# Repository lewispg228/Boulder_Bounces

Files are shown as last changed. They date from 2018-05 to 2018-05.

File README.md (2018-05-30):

# Boulder Bounces
The Museum of Boulder exhibit designers have paired with SparkFun to create Boulder Bounces: a mashup of Simon Says on trampolines. With sounds and spot lights triggering for every jump in the room, the exhibit is a bouncy blast for all ages.

Also includes slightly different code for the "Mighty Mini" and "Hop & Hear".

For a more in depth written post about the design choices, challenges, and future developments please visit the Enginursday blog post here:

https://www.sparkfun.com/news/2696

Visit this website for more info and links to all the products used in this project:

https://www.sparkfun.com/boulderbounces

To learn more about the Museum of Boulder and buy tickets please visit their website here:

https://www.museumofboulder.org

SparkFun products used in this project:

[Arduino Pro Mini 328 - 5V/16MHz](https://www.sparkfun.com/products/11113)

[Ultrasonic Sensor - HC-SR04](https://www.sparkfun.com/products/13959)

[Tsunami Super WAV Trigger](https://www.sparkfun.com/products/13810)

[SparkFun Beefcake Relay Control Kit Ver. 2.0](https://www.sparkfun.com/products/13815)

[SparkFun Music Instrument Shield](https://www.sparkfun.com/products/10587)

[7-Segment Display - 6.5" (Red)](https://www.sparkfun.com/products/8530)

[SparkFun Large Digit Driver](https://www.sparkfun.com/products/13279)

[SparkFun Noisy Cricket Stereo Amplifier - 1.5W](https://www.sparkfun.com/products/14475)

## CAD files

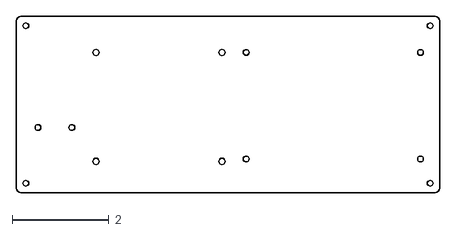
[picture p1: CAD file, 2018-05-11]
HARDWARE/MAIN_BASE/MAIN_BASE_2.dxf
8.75 x 3.65

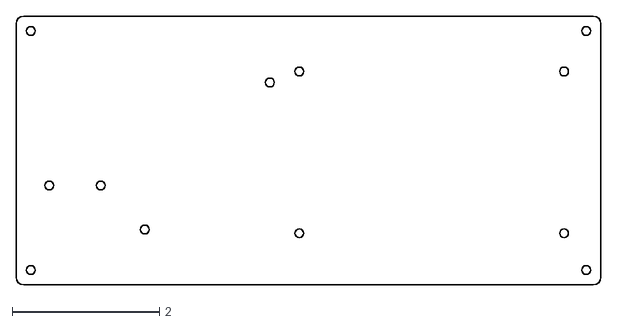
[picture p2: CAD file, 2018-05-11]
HARDWARE/MAIN_BASE/MAIN_BASE.dxf
7.95 x 3.65

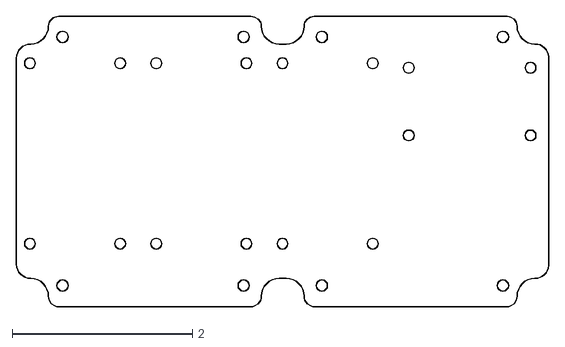
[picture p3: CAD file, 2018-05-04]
HARDWARE/Trampoline_Lights_BASE/Trampoline_Lights_BASE.dxf
5.90 x 3.22

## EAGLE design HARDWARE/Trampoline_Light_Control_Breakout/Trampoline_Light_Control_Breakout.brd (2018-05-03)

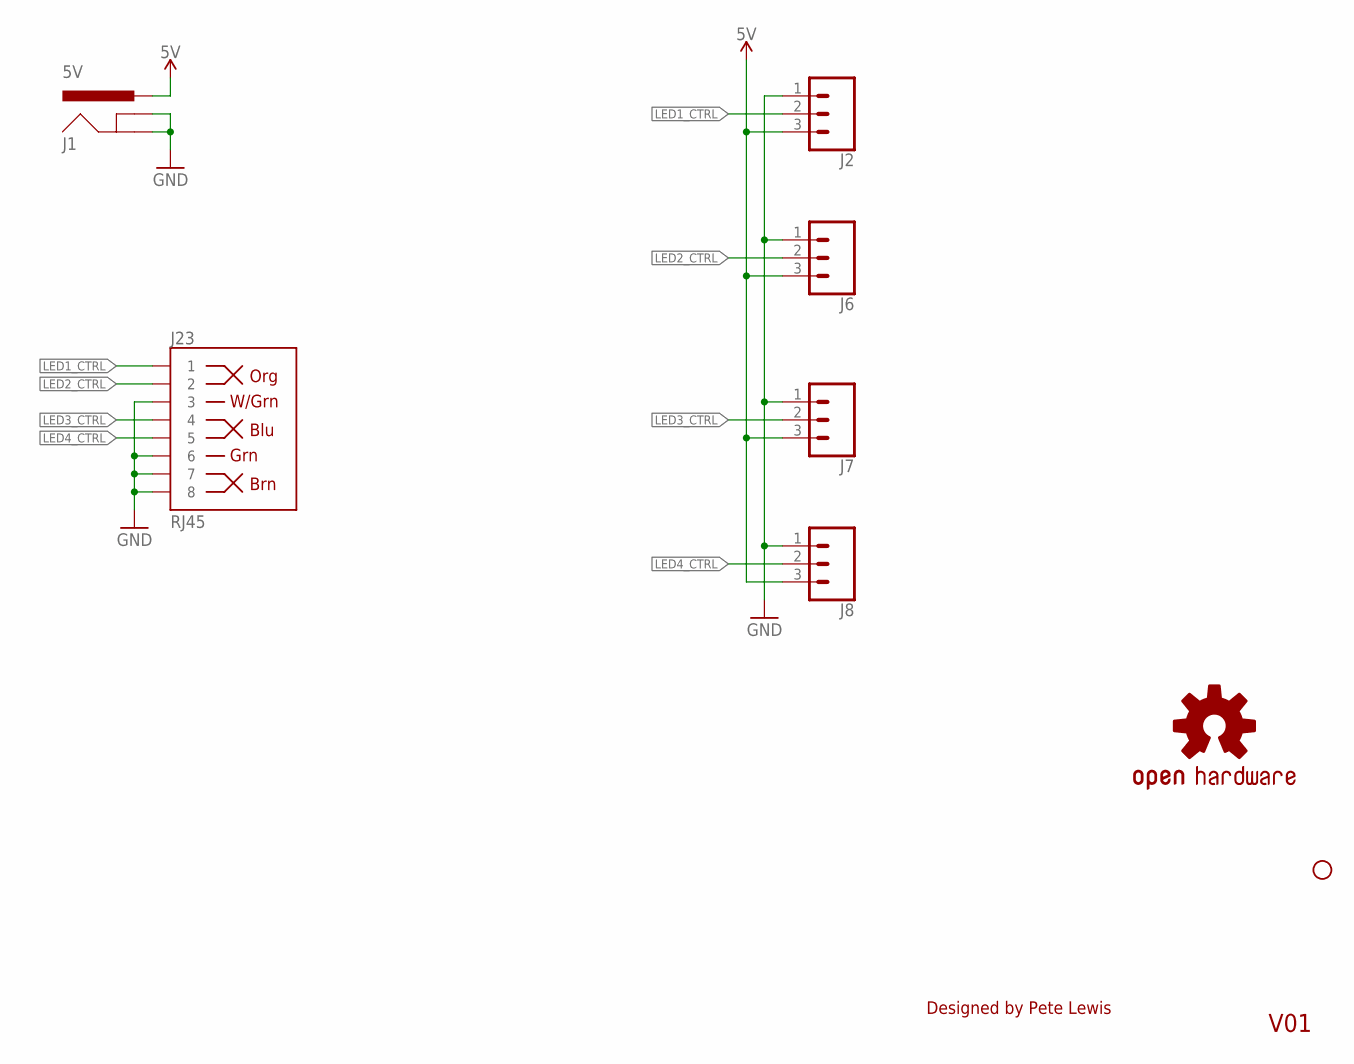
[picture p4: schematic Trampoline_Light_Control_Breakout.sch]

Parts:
J1: 5V; POWER_JACK_PTH_LOCK
J2, J6, J7, J8: CONN_03LONGPADS; 1X03_LONGPADS
J23: RJ45; RJ45-8
JP1: STAND-OFFTIGHTER; STAND-OFF-TIGHTER
LOGO2: OSHW-LOGOS; OSHW-LOGO-S

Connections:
GND: J1.GND, J1.GNDBREAK, J2.1, J6.1, J7.1, J8.1, J23.3, J23.6, J23.7, J23.8
LED1_CTRL: J2.2, J23.1
LED2_CTRL: J6.2, J23.2
LED3_CTRL: J7.2, J23.4
LED4_CTRL: J8.2, J23.5
VCC: J1.PWR, J2.3, J6.3, J7.3, J8.3

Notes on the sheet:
V01
Designed by Pete Lewis

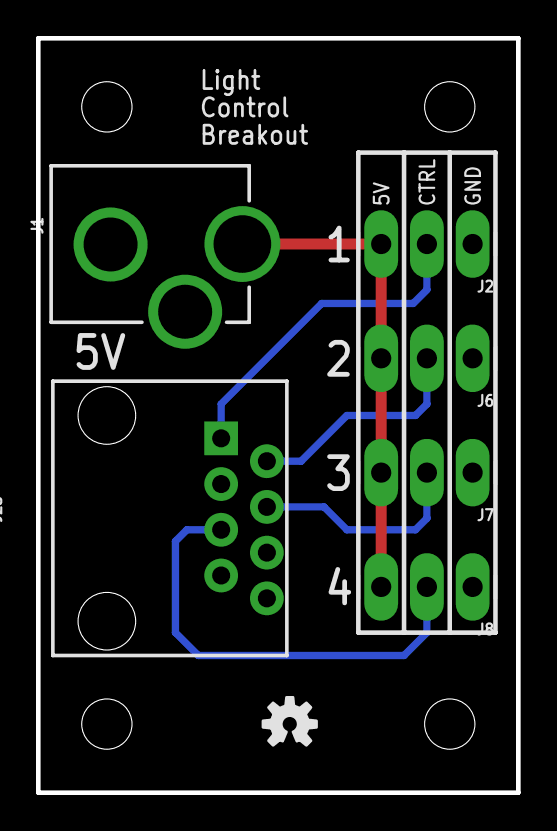
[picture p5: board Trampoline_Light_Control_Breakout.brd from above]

Board: 2 copper layers, 26.7 x 41.9 mm, 11 parts (0 on the bottom side), 6 nets.

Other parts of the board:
JP2, JP3, JP7: STAND-OFFTIGHTER; STAND-OFF-TIGHTER

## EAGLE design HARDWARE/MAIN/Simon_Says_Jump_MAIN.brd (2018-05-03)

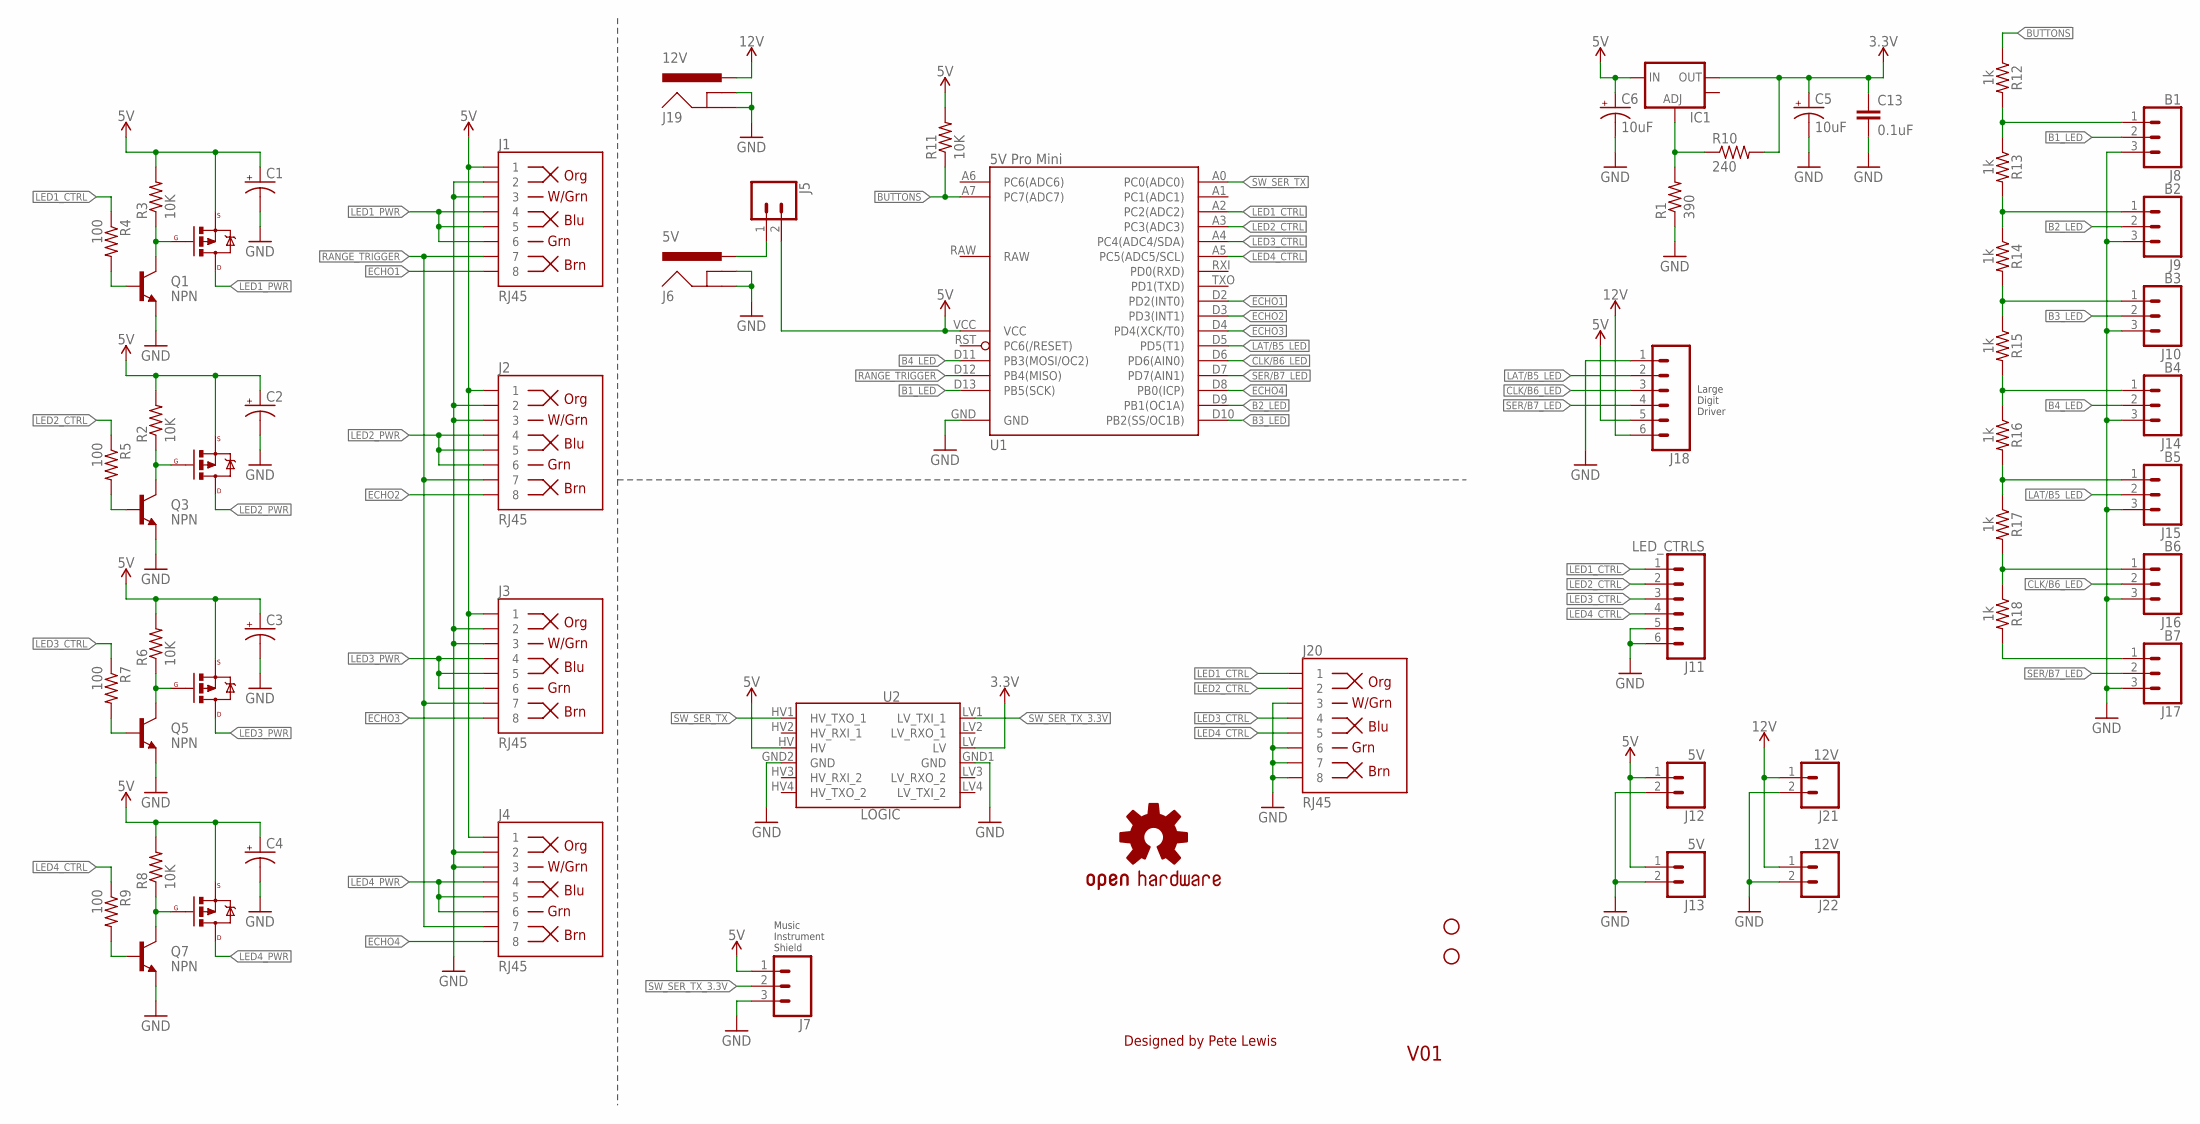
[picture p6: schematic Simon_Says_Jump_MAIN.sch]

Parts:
C1, C2, C3, C4: CAP_POLCPOL-RADIAL-10UF-25V-KIT; CPOL-RADIAL-10UF-25V-KIT
C5, C6: 10uF; EIA3216
C13: 0.1uF; 0603-CAP
IC1: V_REG_LM1117SOT223; SOT223
J1, J2, J3, J4, J20: RJ45; RJ45-8
J5: CONN_02PTH3; 1X02_LONGPADS
J6: 5V; POWER_JACK_PTH_LOCK
J7: CONN_03LONGPADS; 1X03_LONGPADS
J8: B1; 1X03_LONGPADS
J9: B2; 1X03_LONGPADS
J10: B3; 1X03_LONGPADS
J11: LED_CTRLS; 1X06_LONGPADS
J12, J13: 5V; 1X02_LONGPADS
J14: B4; 1X03_LONGPADS
J15: B5; 1X03_LONGPADS
J16: B6; 1X03_LONGPADS
J17: B7; 1X03_LONGPADS
J18: CONN_06LONGPADS; 1X06_LONGPADS
J19: 12V; POWER_JACK_PTH_LOCK
J21, J22: 12V; 1X02_LONGPADS
JP1, JP7: STAND-OFFTIGHTER; STAND-OFF-TIGHTER
LOGO1: OSHW-LOGOL; OSHW-LOGO-L
Q1, Q3, Q5, Q7: NPN; SOT23
Q2, Q4, Q6, Q8: P-Channel MOSFET; TO220V
R1: 390; 0603-RES
R2, R3, R6, R8, R11: 10K; 0603-RES
R4, R5, R7, R9: 100; 0603-RES
R10: 240; 0603-RES
R12, R13, R14, R15, R16, R17, R18: 1k; 0603
U1: 5V Pro Mini; ARDUINO_PRO_MINI-V13_DIP
U2: LOGIC; SPARKFUN_LOGIC_LEVEL_CONVERTER

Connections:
3.3V: C5.A (+), C13.1, IC1.2 (OUT), R10.2, U2.LV
5V: C1.1 (+), C2.1 (+), C3.1 (+), C4.1 (+), C6.A (+), IC1.3 (IN), J1.1, J2.1, J3.1, J4.1, J5.2, J7.1, J12.1, J13.1, J18.5, Q2.3 (S), Q4.3 (S), Q6.3 (S), Q8.3 (S), R2.2, R3.2, R6.2, R8.2, R11.2, U1.VCC, U2.HV
12V: J18.6, J19.PWR, J21.1, J22.1
B1_LED: J8.2, U1.D13 (PB5(SCK))
B2_LED: J9.2, U1.D9 (PB1(OC1A))
B3_LED: J10.2, U1.D10 (PB2(SS/OC1B))
B4_LED: J14.2, U1.D11 (PB3(MOSI/OC2))
BUTTONS: R11.1, R12.1, U1.A7 (PC7(ADC7))
CLK/B6_LED: J16.2, J18.3, U1.D6 (PD6(AIN0))
ECHO1: J1.8, U1.D2 (PD2(INT0))
ECHO2: J2.8, U1.D3 (PD3(INT1))
ECHO3: J3.8, U1.D4 (PD4(XCK/T0))
ECHO4: J4.8, U1.D8 (PB0(ICP))
GND: C1.2 (-), C2.2 (-), C3.2 (-), C4.2 (-), C5.C (-), C6.C (-), C13.2, J1.2, J1.3, J2.2, J2.3, J3.2, J3.3, J4.2, J4.3, J6.GND, J6.GNDBREAK, J7.3, J8.3, J9.3, J10.3, J11.5, J11.6, J12.2, J13.2, J14.3, J15.3, J16.3, J17.3, J18.1, J19.GND, J19.GNDBREAK, J20.3, J20.6, J20.7, J20.8, J21.2, J22.2, Q1.2 (E), Q3.2 (E), Q5.2 (E), Q7.2 (E), R1.1, U1.GND, U2.GND1 (GND), U2.GND2 (GND)
LAT/B5_LED: J15.2, J18.2, U1.D5 (PD5(T1))
LED1_CTRL: J11.1, J20.1, R4.1, U1.A2 (PC2(ADC2))
LED1_PWR: J1.4, J1.5, J1.6, Q2.2 (D)
LED2_CTRL: J11.2, J20.2, R5.1, U1.A3 (PC3(ADC3))
LED2_PWR: J2.4, J2.5, J2.6, Q4.2 (D)
LED3_CTRL: J11.3, J20.4, R7.1, U1.A4 (PC4(ADC4/SDA))
LED3_PWR: J3.4, J3.5, J3.6, Q6.2 (D)
LED4_CTRL: J11.4, J20.5, R9.1, U1.A5 (PC5(ADC5/SCL))
LED4_PWR: J4.4, J4.5, J4.6, Q8.2 (D)
unnamed: Q3.3 (C), Q4.1 (G), R2.1
unnamed: J8.1, R12.2, R13.1
unnamed: Q1.1 (B), R4.2
unnamed: J5.1, J6.PWR
unnamed: Q1.3 (C), Q2.1 (G), R3.1
unnamed: J9.1, R13.2, R14.1
unnamed: Q3.1 (B), R5.2
unnamed: Q5.3 (C), Q6.1 (G), R6.1
unnamed: Q5.1 (B), R7.2
unnamed: Q7.3 (C), Q8.1 (G), R8.1
unnamed: IC1.1 (ADJ), R1.2, R10.1
unnamed: Q7.1 (B), R9.2
unnamed: J10.1, R14.2, R15.1
unnamed: J14.1, R15.2, R16.1
unnamed: J15.1, R16.2, R17.1
unnamed: J16.1, R17.2, R18.1
unnamed: J17.1, R18.2
RANGE_TRIGGER: J1.7, J2.7, J3.7, J4.7, U1.D12 (PB4(MISO))
SER/B7_LED: J17.2, J18.4, U1.D7 (PD7(AIN1))
SW_SER_TX: U1.A0 (PC0(ADC0)), U2.HV1 (HV_TXO_1)
SW_SER_TX_3.3V: J7.2, U2.LV1 (LV_TXI_1)

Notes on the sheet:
V01
Designed by Pete Lewis
Music Instrument Shield
Large Digit Driver

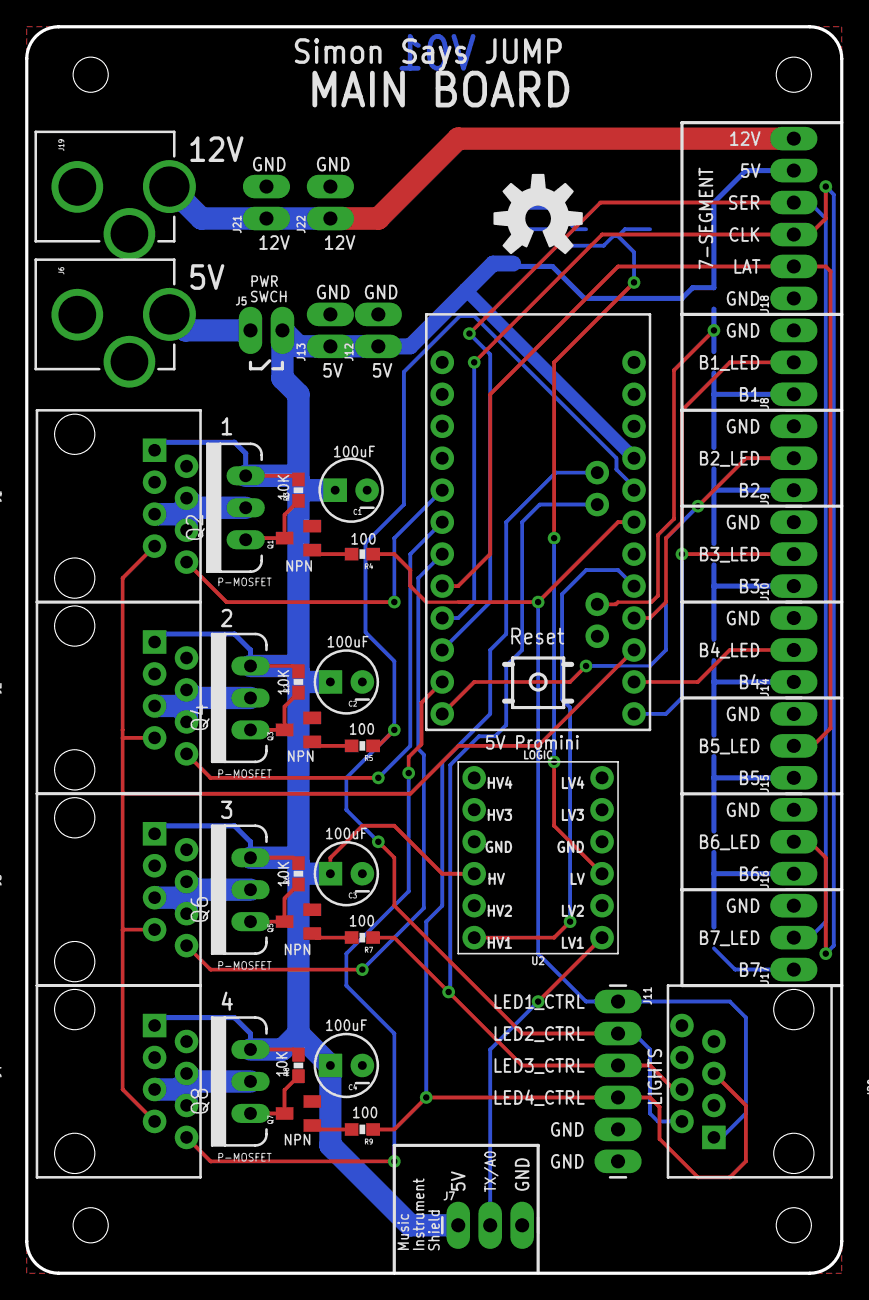
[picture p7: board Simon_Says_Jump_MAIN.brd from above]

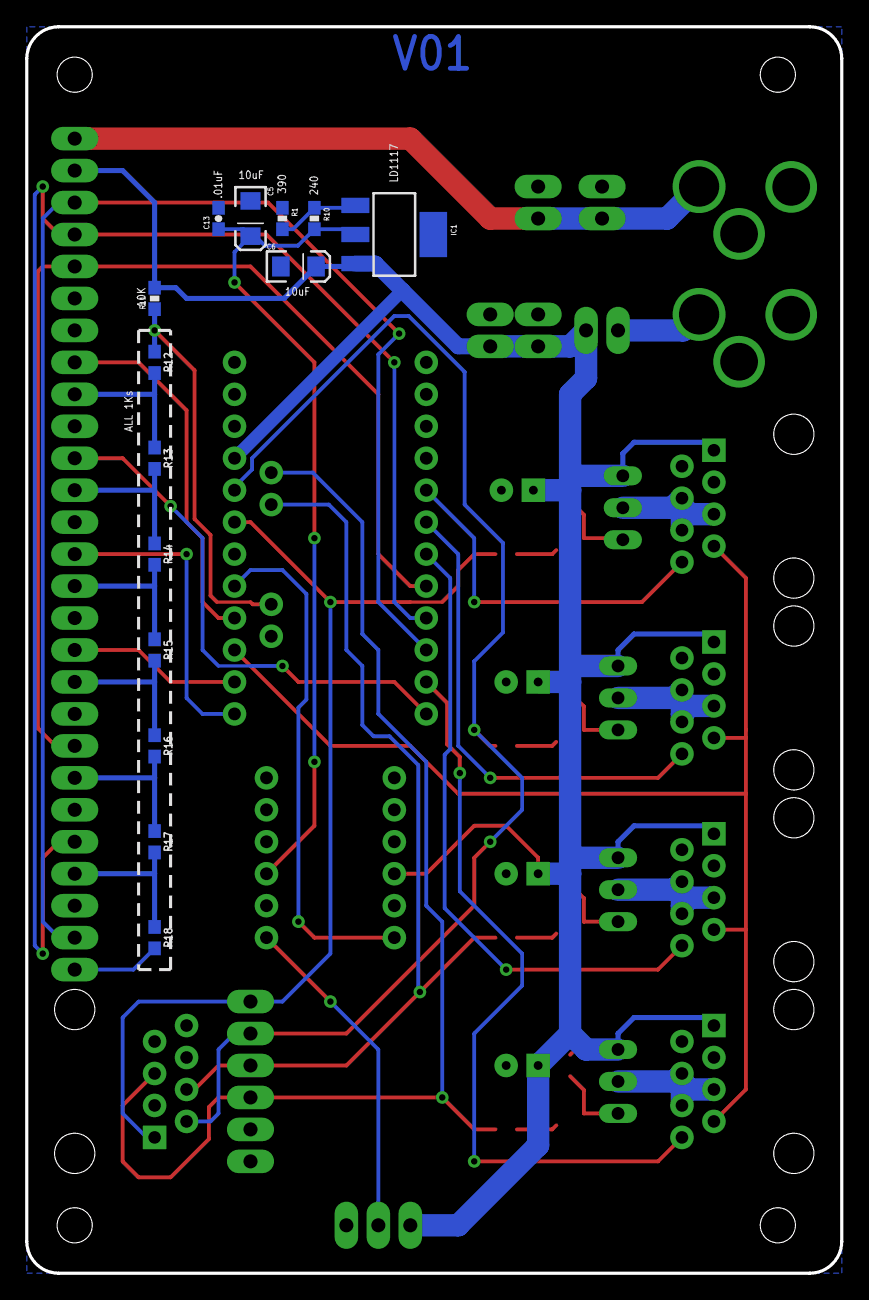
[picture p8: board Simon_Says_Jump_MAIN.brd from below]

Board: 2 copper layers, 64.8 x 99.1 mm, 63 parts (14 on the bottom side), 44 nets.

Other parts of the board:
JP2, JP3: STAND-OFFTIGHTER; STAND-OFF-TIGHTER

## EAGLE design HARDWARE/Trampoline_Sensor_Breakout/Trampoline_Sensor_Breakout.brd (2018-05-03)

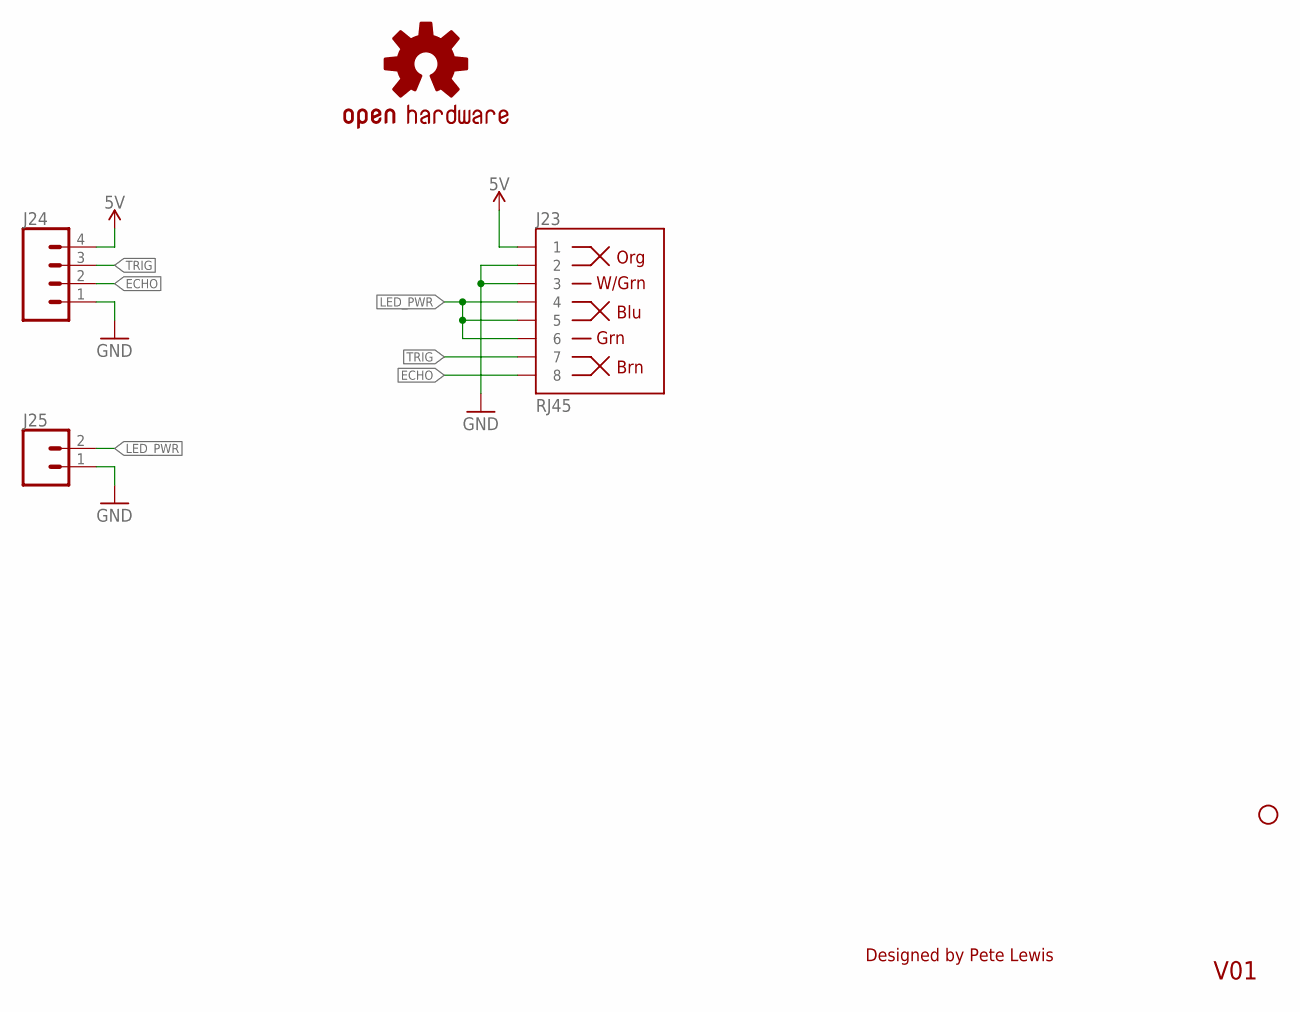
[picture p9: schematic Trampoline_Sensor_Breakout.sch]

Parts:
J23: RJ45; RJ45-8
J24: CONN_04LONGPADS; 1X04_LONGPADS
J25: CONN_02PTH3; 1X02_LONGPADS
JP8: STAND-OFFTIGHTER; STAND-OFF-TIGHTER
LOGO2: OSHW-LOGOS; OSHW-LOGO-S

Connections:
5V: J23.1, J24.4
ECHO: J23.8, J24.2
GND: J23.2, J23.3, J24.1, J25.1
LED_PWR: J23.4, J23.5, J23.6, J25.2
TRIG: J23.7, J24.3

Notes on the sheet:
V01
Designed by Pete Lewis

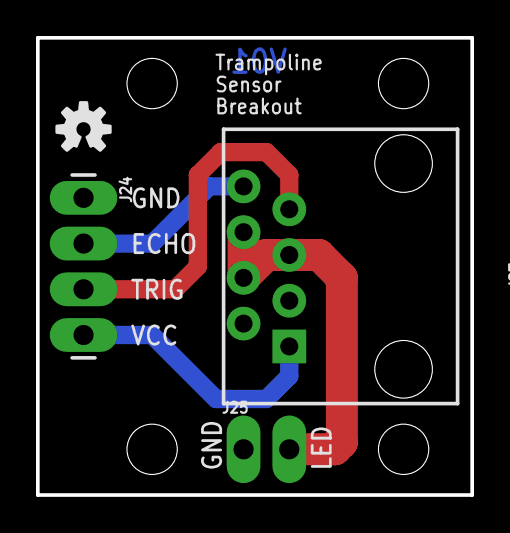
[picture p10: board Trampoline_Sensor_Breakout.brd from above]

Board: 2 copper layers, 24.1 x 25.4 mm, 8 parts (0 on the bottom side), 5 nets.

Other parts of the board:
JP4, JP5, JP6: STAND-OFFTIGHTER; STAND-OFF-TIGHTER

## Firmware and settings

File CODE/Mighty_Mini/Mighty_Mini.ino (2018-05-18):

/*
 Started: 6-19-2007
 Spark Fun Electronics
 Nathan Seidle
 
 Simon Says is a memory game. Start the game by pressing one of the four buttons. When a button lights up, 
 press the button, repeating the sequence. The sequence will get longer and longer. The game is won after 
 13 rounds.
 
 This code is public domain but you buy me a beer if you use this and we meet someday (Beerware license).
 
 Simon Says game originally written in C for the PIC16F88.
 Ported for the ATmega168, then ATmega328, then Arduino 1.0.
 Fixes and cleanup by Joshua Neal <joshua[at]trochotron.com>
 
 Generates random sequence, plays music, and displays button lights.
 
 Simon tones from Wikipedia
 - A (red, upper left) - 440Hz - 2.272ms - 1.136ms pulse
 - a (green, upper right, an octave higher than A) - 880Hz - 1.136ms,
 0.568ms pulse
 - D (blue, lower left, a perfect fourth higher than the upper left) 
 587.33Hz - 1.702ms - 0.851ms pulse
 - G (yellow, lower right, a perfect fourth higher than the lower left) - 
 784Hz - 1.276ms - 0.638ms pulse
 
 The tones are close, but probably off a bit, but they sound all right.
 
 The old version of SparkFun simon used an ATmega8. An ATmega8 ships
 with a default internal 1MHz oscillator.  You will need to set the
 internal fuses to operate at the correct external 16MHz oscillator.
 
 Original Fuses:
 avrdude -p atmega8 -P lpt1 -c stk200 -U lfuse:w:0xE1:m -U hfuse:w:0xD9:m
 
 Command to set to fuses to use external 16MHz: 
 avrdude -p atmega8 -P lpt1 -c stk200 -U lfuse:w:0xEE:m -U hfuse:w:0xC9:m
 
 The current version of Simon uses the ATmega328. The external osciallator
 was removed to reduce component count.  This version of simon relies on the
 internal default 1MHz osciallator. Do not set the external fuses.

 */


   /*
 Controlling large 7-segment displays
 By: Nathan Seidle
 SparkFun Electronics
 Date: February 25th, 2015
 License: This code is public domain but you buy me a beer if you use this and we meet someday (Beerware license).

 This code demonstrates how to post two numbers to a 2-digit display usings two large digit driver boards.

 Here's how to hook up the Arduino pins to the Large Digit Driver IN

 Arduino pin 6 -> CLK (Green on the 6-pin cable)
 5 -> LAT (Blue)
 7 -> SER on the IN side (Yellow)
 5V -> 5V (Orange)
 Power Arduino with 12V and connect to Vin -> 12V (Red)
 GND -> GND (Black)

 There are two connectors on the Large Digit Driver. 'IN' is the input side that should be connected to
 your microcontroller (the Arduino). 'OUT' is the output side that should be connected to the 'IN' of addtional
 digits.

 Each display will use about 150mA with all segments and decimal point on.

*/




#include "hardware_versions.h"

#define MODE_DUCK  0
#define MODE_DRUMS  1

#define DUCK_TRACKS 8
#define DRUMS_TRACKS 10

// Game state variables
byte gameMode = MODE_DUCK;

int button_leds[] = {13,10}; // 1 and 3

// TRAMPOLINE EXTENTION STUFF
  
// FOUR variables to keep track of each trampoline status.
// To register a true jump on a trampoline, 
// we are looking for when the trampoline changes from HIGH (not standing on it) to LOW (standing on it)
// This is different than bressing a button,
// Because when pressing a button, we wait for the release moment to actually trigger the button
// When jumping on trampolines, we want to the trigger point to be exactly when a tampoline transitions
// from HIGH to LOW. This means that the player could still hold the previous trampoline LOW 
// (i.e. that could have one foot on the previous step)
// and still use their other foot to trigger the next step.
// These four variables keep track of how long each trampoline has been in the HIGH state
// Doing this, allows us to require that a trampoline be in the HIGH state for a certain
// amount of time. This helps debounce and prevent false triggering.

long T_distance[4] = {0,0,0,0};
boolean T_boolean[4] = {0,0,0,0};

// 3/2/2016, initiating all of these to 0, so that you can start a round standing on one trampoline, or any combo.

int HIGH_COUNTER_RED = 0;
int HIGH_COUNTER_GREEN = 0;
int HIGH_COUNTER_BLUE = 0;
int HIGH_COUNTER_YELLOW = 0;

// ULTRA_SONIC RANGE FINDER SETUP STUFF
#define trigPin 12
#define echoPin 2
#define echoPin2 3
#define echoPin3 4
#define echoPin4 8

int mode_ADC_reading;
int button_value[7] = {90, 168, 234, 290, 339, 381, 419};

byte bounceCount = 0;
boolean bounceCount_active = false;

long threshold_up = 1000;

int group_start_track = 70; // start on ducks - if no button is pressed on a hard micro reset
int group_tracks = 6;
int delay_ms_tsunami_com = 100;

#include <Tsunami.h>            // Include the Tsunami library header
#include <AltSoftSerial.h>    // Optional for using AltSoftSerial

Tsunami tsunami;                // Our Tsunami object

int global_static_timeout_count; // this climbs as we see no jumping at all (people have stopped jumping)
#define GLOBAL_STATIC_TIMEOUT_LIMIT 3000 // about 10 seconds


//GPIO declarations
//-=-=-=-=-=-=-=-=-=-=-=-=-=-=-=-=-=-=-=-=-=-=-=-=
byte segmentClock = 6;
byte segmentLatch = 5;
byte segmentData = 7;


void setup()
{
  //Setup hardware inputs/outputs. These pins are defined in the hardware_versions header file

  // button LEDs aka mode leds
  for(int i = 0 ; i < 2 ; i++ )
  {
    pinMode(button_leds[i], OUTPUT);
    digitalWrite(button_leds[i], LOW);
  }

  pinMode(segmentClock, OUTPUT);
  pinMode(segmentData, OUTPUT);
  pinMode(segmentLatch, OUTPUT);

  digitalWrite(segmentClock, LOW);
  digitalWrite(segmentData, LOW);
  digitalWrite(segmentLatch, LOW);
  
  // ULTRA_SONIC RANGE FINDER SETUP STUFF
  pinMode(trigPin, OUTPUT);
  pinMode(echoPin, INPUT);
  pinMode(echoPin2, INPUT);
  pinMode(echoPin3, INPUT);
  pinMode(echoPin4, INPUT);  

  Serial.begin(115200);
  Serial.println("HOP AND HEAR Debug ON"); 

  tsunami.start();
  delay(delay_ms_tsunami_com);
  // Send a stop-all command and reset the sample-rate offset, in case we have
  //  reset while the Tsunami was already playing.
  tsunami.stopAllTracks();
  delay(delay_ms_tsunami_com);  
  tsunami.samplerateOffset(0, 0);
  delay(delay_ms_tsunami_com);  
  // disable track reporting from the Tsunami
  tsunami.setReporting(false);
  delay(delay_ms_tsunami_com);  
  // Call update on the Tsunami to keep the track playing status current.
  tsunami.update();  
  delay(delay_ms_tsunami_com);  
  tsunami.masterGain(0, 0);              // Reset the master gain to 0dB
  delay(delay_ms_tsunami_com);  
  test_audio_playback();

  clear_display();
  delay(1000);
  set_button_leds();
}

void loop()
{
  checkButton_trampoline(); // this function fires the sounds and changes modes
    
  if(global_static_timeout_count > GLOBAL_STATIC_TIMEOUT_LIMIT)
  {
    Serial.println("Global static timeout");
    global_static_timeout_count = 0; // reset
    bounceCount = 0; // reset
    bounceCount_active = false;
    clear_display();
    gameMode = MODE_DUCK;
    set_button_leds();
    delay(1000);
  }  
}


// Returns a '1' bit in the position corresponding to CHOICE_RED, CHOICE_GREEN, etc.
// but the FLAG of that button must have been set to

byte checkButton_trampoline(void)
{
  byte CHOICE = CHOICE_NONE; // if nothing is pressed
  //ultra_sonic_test();
  //digitalReadTrampoline_test();
  read_T_distances();
  set_T_booleans();
  //print_data();
  /////////////////RED
  if ((T_boolean[0] == 0) && (HIGH_COUNTER_RED > 5)) // if FLAG_RED is set to true, that means that it has been release at some point previously.
  {
    HIGH_COUNTER_RED = 0; // reset counter
    play_track(group_start_track + random(0, (group_tracks)));
    CHOICE = CHOICE_RED;
    if(bounceCount_active == true)
    {
      bounceCount++;
      showNumber(bounceCount);
      Serial.println(bounceCount);      
    }
  }
  
  if((T_boolean[0] == 1) && (HIGH_COUNTER_RED < 6)) HIGH_COUNTER_RED++;
  
  //GLOBAL STATIC TIMEOUT STUFF ////////////////////////////////////////////
  if(CHOICE == CHOICE_NONE) global_static_timeout_count++; // keep count
  else global_static_timeout_count = 0; // reset
  //Serial.println(global_static_timeout_count);
  
  return(CHOICE); // If no button is pressed, this will be default CHOICE_NONE, but if something is pressed, then it will be set in the IFs above.
}

boolean check_mode_buttons()
{
  mode_ADC_reading = analogRead(A7);
  if(mode_ADC_reading > 900) return false; // no button being pressed
  else
  {
    Serial.println(mode_ADC_reading);
    // take some more readings and average them, to avoid false button presses.
    // this requires that the button be held down a little more solidly
    int total_readings = 0;
    for (int i = 0 ; i < 10 ; i++)
    {
      total_readings += analogRead(A7);
      delay(10);
    }
    mode_ADC_reading = (total_readings/10);
    Serial.println(mode_ADC_reading);
      if((mode_ADC_reading > (button_value[0] - 5)) && (mode_ADC_reading < (button_value[0] + 5)))
      {
        gameMode = MODE_DUCK;
        Serial.println("DUCK");
        group_start_track = 70;
        group_tracks = DUCK_TRACKS;
        set_button_leds();
        return true;
      }
      
      else if((mode_ADC_reading > (button_value[2] - 5)) && (mode_ADC_reading < (button_value[2] + 5)))
      {
        gameMode = MODE_DRUMS;
        Serial.println("DRUMS");
        group_start_track = 60;
        group_tracks = DRUMS_TRACKS;     
        set_button_leds();   
        return true;
      }

      else if((mode_ADC_reading > (button_value[4] - 5)) && (mode_ADC_reading < (button_value[4] + 5)))
      {
        Serial.println("BOUNCE_COUNT_RESET");
        bounceCount = 0;     
        bounceCount_active = true;
        showNumber(bounceCount);
        return true;
      }      
                   
      else
      {
        Serial.println("BAD VALUE");
        return false;
      }
  }
}

void mode_button_calibration()
{
  Serial.println(analogRead(A7));
  delay(50);
  /*
   * 
   * These are the readings I'm seeing on my first MAIN board built up.
   * open: 1023
   * B1: 90
   * B2: 168
   * B3: 234
   * B4: 290
   * B5: 339
   * B6: 381
   * B7: 419
   */
}

void test_audio_playback()
{
  for(int i = 10 ; i < 11 ; i++)
  {
    Serial.print("track: ");
    Serial.println(i);
    tsunami.trackGain(i, -5);
    delay(delay_ms_tsunami_com);
    tsunami.trackPlayPoly(i, 0, false); 
    delay(1000);                  
  }
}

void play_track(int track)
{
    Serial.print("track: ");
    Serial.println(track);
    tsunami.trackGain(track, -5);
    delay(delay_ms_tsunami_com);
    tsunami.trackPlayPoly(track, 0, false); 
    delay(delay_ms_tsunami_com);
}


//Takes a number and displays 2 numbers. Displays absolute value (no negatives)
void showNumber(float value)
{
  int number = abs(value); //Remove negative signs and any decimals

  //Serial.print("number: ");
  //Serial.println(number);

  for (byte x = 0 ; x < 2 ; x++)
  {
    int remainder = number % 10;

    postNumber(remainder, false);

    number /= 10;
  }

  //Latch the current segment data
  digitalWrite(segmentLatch, LOW);
  digitalWrite(segmentLatch, HIGH); //Register moves storage register on the rising edge of RCK
}

//Given a number, or '-', shifts it out to the display
void postNumber(byte number, boolean decimal)
{
  //    -  A
  //   / / F/B
  //    -  G
  //   / / E/C
  //    -. D/DP

#define a  1<<0
#define b  1<<6
#define c  1<<5
#define d  1<<4
#define e  1<<3
#define f  1<<1
#define g  1<<2
#define dp 1<<7

  byte segments;

  switch (number)
  {
    case 1: segments = b | c; break;
    case 2: segments = a | b | d | e | g; break;
    case 3: segments = a | b | c | d | g; break;
    case 4: segments = f | g | b | c; break;
    case 5: segments = a | f | g | c | d; break;
    case 6: segments = a | f | g | e | c | d; break;
    case 7: segments = a | b | c; break;
    case 8: segments = a | b | c | d | e | f | g; break;
    case 9: segments = a | b | c | d | f | g; break;
    case 0: segments = a | b | c | d | e | f; break;
    case 10: segments = 0; break;
    case 'c': segments = g | e | d; break;
    case '-': segments = g; break;
  }

  if (decimal) segments |= dp;

  //Clock these bits out to the drivers
  for (byte x = 0 ; x < 8 ; x++)
  {
    digitalWrite(segmentClock, LOW);
    digitalWrite(segmentData, segments & 1 << (7 - x));
    digitalWrite(segmentClock, HIGH); //Data transfers to the register on the rising edge of SRCK
  }
}

void clear_display(void)
{
  
    //Clock these bits out to the drivers
  for (byte x = 0 ; x < 8 ; x++)
  {
    digitalWrite(segmentClock, LOW);
    digitalWrite(segmentData, LOW);
    digitalWrite(segmentClock, HIGH); //Data transfers to the register on the rising edge of SRCK
  }

  //Latch the current segment data
  digitalWrite(segmentLatch, LOW);
  digitalWrite(segmentLatch, HIGH); //Register moves storage register on the rising edge of RCK

    //Clock these bits out to the drivers
  for (byte x = 0 ; x < 8 ; x++)
  {
    digitalWrite(segmentClock, LOW);
    digitalWrite(segmentData, LOW);
    digitalWrite(segmentClock, HIGH); //Data transfers to the register on the rising edge of SRCK
  }

  //Latch the current segment data
  digitalWrite(segmentLatch, LOW);
  digitalWrite(segmentLatch, HIGH); //Register moves storage register on the rising edge of RCK  
}


void set_button_leds(void)
{
  int select;
  for(int i = 0 ; i < 2 ; i++ ) 
  {
    digitalWrite(button_leds[i], LOW);
  }
  
  if(gameMode == MODE_DUCK) select = 0;
  else if(gameMode == MODE_DRUMS) select = 1;
  
  digitalWrite(button_leds[select], HIGH);
}

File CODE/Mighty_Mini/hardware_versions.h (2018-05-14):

/*
 Started: 12-26-2012
 Spark Fun Electronics

 The SparkFun Simon Says game has been through dozens of revisions over the years. This header
 file attempts to map and support all the different hardware versions.
*/

#define CHOICE_OFF      0 //Used to control LEDs
#define CHOICE_NONE     0 //Used to check buttons
#define CHOICE_RED	(1 << 0)
#define CHOICE_GREEN	(1 << 1)
#define CHOICE_BLUE	(1 << 2)
#define CHOICE_YELLOW	(1 << 3)


// Uncomment one of the following, corresponding to the board you have.
#define BOARD_REV_2_3_2011 //Works with PTH board label '2-3-2011'
//#define BOARD_REV_4_9_2009   //Works with SMD simoon board label '4/9/2009' and '9/7/11'
//#define BOARD_REV_6_25_2008

#ifdef BOARD_REV_2_3_2011
  // LED pin definitions, these are Arduino pins, not ATmega pins
  #define LED_RED     A2
  #define LED_BLUE    A3
  #define LED_GREEN   A4
  #define LED_YELLOW  A5
  
  // Button pin definitions
  #define BUTTON_RED    9
  #define BUTTON_GREEN  2
  #define BUTTON_BLUE   12
  #define BUTTON_YELLOW 6
  
  // Buzzer pin definitions
  #define BUZZER1  4
  #define BUZZER2  7
#endif  // End definition for BOARD_REV_2_3_2011

#ifdef BOARD_REV_4_9_2009
  // LED pin definitions, these are Arduino pins, not ATmega pins
  #define LED_BLUE     13 //PORTB.5
  #define LED_YELLOW   5 //PORTD.5
  #define LED_RED      10 //PORTB.2
  #define LED_GREEN    2 //PORTD.2
  
  // Button pin definitions
  #define BUTTON_RED     8 //PINB.0
  #define BUTTON_GREEN   9 //PINB.1
  #define BUTTON_BLUE    7 //PIND.7
  #define BUTTON_YELLOW  6 //PIND.6
  
  // Buzzer pin definitions
  #define BUZZER1  3 //PORTD.3
  #define BUZZER2  4 //PORTD.4
#endif  // End define for BOARD_REV_4_9_2009

#ifdef BOARD_REV_6_25_2008
  // LED pin definitions, these are Arduino pins, not ATmega pins
  #define LED_RED     A3 //PORTC.3
  #define LED_GREEN   2 //PORTD.2
  #define LED_BLUE    A0 //PORTC.0
  #define LED_YELLOW  5 //PORTD.5
  
  // Button pin definitions
  #define BUTTON_RED     A2 //PINC.2
  #define BUTTON_GREEN   A5 //PINC.5
  #define BUTTON_BLUE    A1 //PINC.1
  #define BUTTON_YELLOW  6 //PIND.6
  
  // Buzzer pin definitions
  #define BUZZER1 3 //PORTD.3
  #define BUZZER2 4 //PORTD.4
#endif  // End define for BOARD_REV_6_25_2008

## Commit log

2018-04-27 main board started
    includes:
    -RJ45 connectors to each trampoline
    -3pin header to connecto to music instrument shield
    -RFM69 breakout board for wirelessly talking to overhead lighting system
    -optional power switch header to potentially bring to toggle on a panel mount switch mounted elsewhere on the enclosure
    -high side switches for LED power control
    -buzzer and switch
    [Simon_Says_Jump.brd, Simon_Says_Jump.sch]
2018-04-30 logic level converters for the range finders
    They need 5V Logic on trigger and echo pins.
    Also, they're gonna need power (durp), so I stole one of the GND lines in the ethernet connectors/cables to be a dedicated 5V (aka RAW) to power the range sensors.
    [Simon_Says_Jump.brd, Simon_Says_Jump.sch]
2018-05-01 About to switch to 3 trampoline control
    Thought I'd do a commit here, because this could be a god fork point for the SFE installed 4-trampoline setup.
    [Simon_Says_Jump.brd, Simon_Says_Jump.sch]
2018-05-02 Ready for layout
    Opted to keep 4 trampoline/led controls. I ended up using some of the LED control lines as also control lines to the 7-segment, because I won't need to use both of these at the same time.
    The toddler trampline is the only one that uses the 7-segment, and it will only use 2 buttons, so button 5,6,7 can be used for 7-segment.
    Also added in 12V barrel jack input for 7-segment.
    -added ethernet connector for control cable to overhead lights. These IO will control the beefcake relay boards that live up in the rafters with the can lights.
    [Simon_Says_Jump.brd, Simon_Says_Jump.sch]
2018-05-02 routing in progress 30 airwires left
    [Simon_Says_Jump.brd]
2018-05-02 more layout coming along
    [Simon_Says_Jump.brd]
2018-05-03 Layout on main board complete
    [Simon_Says_Jump.brd, Simon_Says_Jump.sch]
2018-05-03 Added in trampoline sensor breakout
    Each trampoline will need one of these. It has the 4-pin header to mate directly with the Ultrasonic Range Finders (Facing upward).
    Includes 4 standoffs for mounting to "arm" off of trampoline pole.
    [Trampoline_Sensor_Breakout.brd, Trampoline_Sensor_Breakout.sch]
2018-05-03 moving main board into folder and renaming MAIN
    [Simon_Says_Jump_MAIN.brd, Simon_Says_Jump_MAIN.sch]
2018-05-03 added light control breakout
    includes 5V barrel jack input and nice 3-pin headers for each beefcake relay connections
    [Trampoline_Light_Control_Breakout.brd, Trampoline_Light_Control_Breakout.sch]
2018-05-04 started mini library with "board" packages for creating bases on lazer
2018-05-04 added light BASE ready for lazering
    [Trampoline_Lights_BASE.brd]
2018-05-04 Lights BASE - moved to BIG RED ENCLOSURE outer dimension
    This should now fit into the SparkFun big red enclosure box
    https://www.sparkfun.com/products/11366
    [Trampoline_Lights_BASE.brd]
2018-05-04 exp dxf for lazering
    [Trampoline_Lights_BASE.dxf]
2018-05-04 MAIN BASE coming together
    [MAIN_BASE.brd]
2018-05-10 Added noisy cricket to mini boards library for bases design work
2018-05-10 added noisey cricket to base
    [MAIN_BASE.brd]
2018-05-11 Base_2 for those stations that need tsunamis
    also exported to dxf for lasering
    [MAIN_BASE.dxf, MAIN_BASE_2.brd, MAIN_BASE_2.dxf]
2018-05-11 Bringing in current code from SFE trampoline installation
2018-05-11 midi reset on D7
    [Simon_Trampolines.ino]
2018-05-11 Bringing in some initial distance sensor testing code
2018-05-11 distance sensor testing tweaks
    Moved single range read to a function. Tried this out on all 4 ethernet ports and I'm getting good readings. Wahoo!
2018-05-12 moved midi notes into checkButton_trampoline
    this allows for two or more trampolines to trigger at the same time.
    Also added a delay of 5 ms at start of distance read - this seemed to make all readings come back much better.
    locked in notes and bank to GM.
    still currently only messing around with musical instrument mode - need to work out buttons and mode switching
2018-05-14 mode switching bug forgot to leave if statements
    [Simon_Trampolines.ino]
2018-05-14 added setLEDs() back into playback, also changed "maxed out" limits per trampoline
    it was stalling at 6 moves, because each one had already had 2, so I changed the "maxed out" limit to 3,3, and 2
    [Simon_Trampolines.ino]
2018-05-14 memory and free jump are working
    also mode button is swtiching correctly - avoiding loser sound if you select free jump in the middle of a memory game
    [Simon_Trampolines.ino]
2018-05-14 rafter board design
    [RAFTER_1.brd]
2018-05-14 tweaking button mode adc stuff
2018-05-14 trying to filter out bad readings on mode buttons
2018-05-15 all modes working
    strange that coming from wack to memory, it seems to immediately fail.
    [Simon_Trampolines.ino]
2018-05-15 memory now has global timeout to free jump
    it will repeat memory round until global timeout happens.
    note, it's a little longer than GLOBAL_STATIC_TIMEOUT_LIMIT because, it needs to fail a memory game to eventually check that global static timeout. This is okay, it just means that you need to let it sit for 2 fail cycles for it to finally get back to free jump
    [Simon_Trampolines.ino]
2018-05-15 fixed strange wack-a-mole quick looping bug
    I was getting stuck in the while loop in wack a mole, even if check_mode_button was changing MODE. This needed a mode check to also break out of this while loop.
    [Simon_Trampolines.ino]
2018-05-17 tsunami latest firmware im using just to have in case
2018-05-17 mighty mini working
    still need to incorporate mode LEDs, but everything else is working: counts, mode switching, global timeouts, display clearing.
2018-05-18 mode LEDs in simon says working
2018-05-18 mode leds in mighty mini working
2018-05-18 added button led to hop and hear - working
    tweaked button 6 value, it wasn't catching a button press cause it's coming in more like 390
2018-05-19 added window tolerance variable to buttons now it's 10, was 5 before
    [Hop_And_Hear.ino, Simon_Trampolines.ino, UltraSonic_Range.ino]
2018-07-11 fixed "stall out" in add_to_moves()
    -My while(1) loop that keeps calling random until it meets the sequence rules was stalling out sometimes. I changed it to always break out of the while(1) by using an on_deck_buttons array that is adjusted to contain only the "choosable" next two options. This way, it doesn't have to endlessly call random() until it "passes"
    -added more debug about gameboard, add_to_moves logic and more
    -attempted to require the first three buttons in gameBoard to be unique, but it doesn't seem to be working with the few times I tested it. I had a couple repeats.
    -added clear_gameBoard() to more easily watch debug when you play more rounds. zeroing them all out, shows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
    [Simon_Trampolines.ino]
2019-07-16 Adjusting filter to remove other error readings
    After installing the trampolines at SparkFun, there was an occasional reading of 16 that was falsely triggering wrong trampolines. Changed the filter to ignore any readings bleow 50.
    [Simon_Trampolines.ino, UltraSonic_Range.ino]

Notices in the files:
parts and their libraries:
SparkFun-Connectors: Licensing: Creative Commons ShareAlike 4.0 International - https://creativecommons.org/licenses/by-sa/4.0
